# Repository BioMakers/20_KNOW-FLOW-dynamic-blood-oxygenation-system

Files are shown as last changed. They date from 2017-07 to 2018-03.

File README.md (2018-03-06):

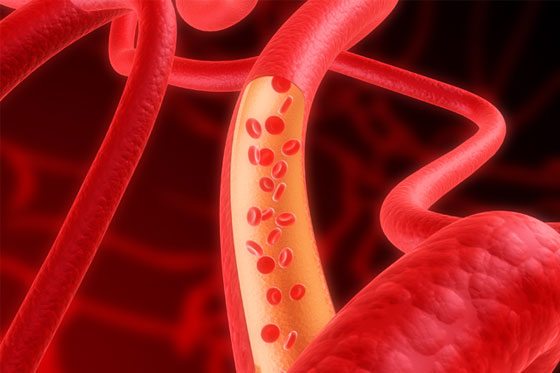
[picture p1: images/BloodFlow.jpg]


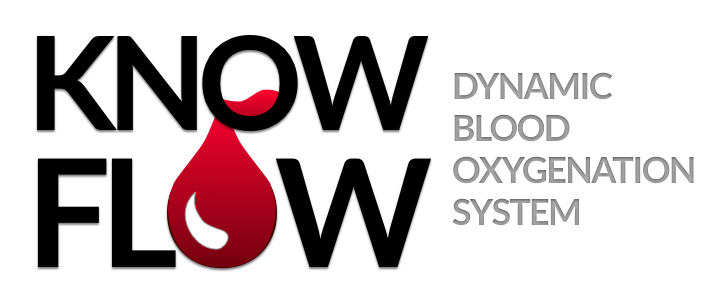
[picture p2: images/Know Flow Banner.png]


## The Idea

The aim of the project is to design and build a low-cost programmable system for flowing liquids through a network of tubes. The flow speed and direction, and fluid mixing via additional injection sites, will be controlled and monitored using a touchscreen interface connected to a peristaltic pump and a 3D-printed syringe pump. Moreover, the touchscreen will have the option for adjustment and display of fluid properties measurable using a pH/pO2/flow sensor array. This will enable control and monitoring of dynamic processes such as changes in blood oxygenation for study of various conditions including sickle cell anaemia and thalassaemia. It will also be possible to artificially perfuse an ex vivo organ such as the mouse or rat liver. In addition, the flow system will be suitable for integration into an imaging device, such as an optoacoustic tomography (OT) scanner, allowing the device to be calibrated for accurate measurements of flow and fluid properties.

## The Team (*Primary contact)

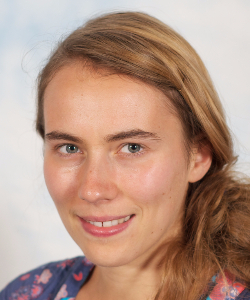
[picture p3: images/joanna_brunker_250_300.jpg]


**Joanna Brunker***     
CRUK Cambridge Institute, University of Cambridge

Jo is a postdoctoral research fellow with a PhD in measuring flow using optoacoustics, so will contribute to the design of the flow setup and subsequent testing in an optoacoustic scanner.

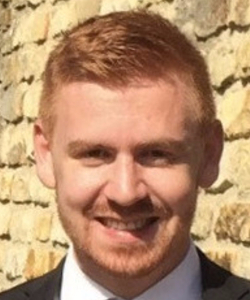
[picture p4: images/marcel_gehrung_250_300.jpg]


**Marcel Gehrung**          
CRUK Cambridge Institute, University of Cambridge

Marcel is a German Masters student studying for six months in Cambridge. He has a background in programming, machine learning, and cell biology, so will help to program the flow system and analyse the multi-parametric biological data.

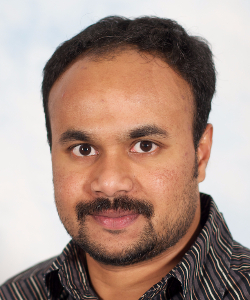
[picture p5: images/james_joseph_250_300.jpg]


**James Joseph**                
Department of Physics, University of Cambridge

James built optoacoustic imaging systems during his PhD, and is characterising imaging system stability for his postdoctoral research. He will therefore contribute to the design and engineering of the flow system and reliability testing. James also has experience with 3D printing.

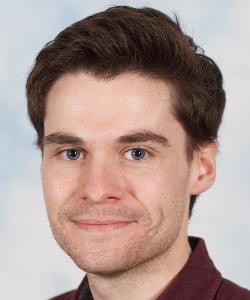
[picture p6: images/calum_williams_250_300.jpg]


**Calum Williams**
Department of Engineering, University of Cambridge

Calum’s post-doc follows his PhD in optical engineering, in which he fabricated and characterised various optical devices. He will contribute to 3D printing, programming, and optical sensing.

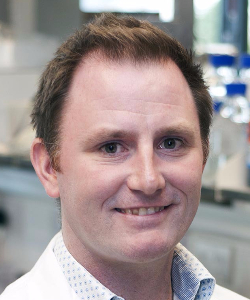
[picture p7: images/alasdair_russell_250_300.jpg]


**Alasdair Russell**          
CRUK Cambridge Institute, University of Cambridge

Al is Head of Pre-Clinical Genome Editing at the CRUK Cambridge Institute. He has a PhD involving haematology, so will contribute expertise on blood properties, help to analyse blood measurements, and direct the development of the flow system for additional haematological applications.

## Project proposal

### Problem and biological system

The blood circulation system plays a critical role in the function of healthy and diseased organisms. Assessment of blood flow, blood oxygenation and tissue perfusion is key to understanding numerous conditions ranging from sickle-cell anaemia to tumour hypoxia. Various techniques, including Doppler ultrasound and laser Doppler, exist for non-invasive assessment of flow in the blood circulation system. Emerging techniques, such as optoacoustic tomography (OT), have the potential to characterise blood absorption enabling measurement of oxygen concentration. However, without independent ex vivo assessment of flow, oxygenation and perfusion, these in vivo measurements remain un-calibrated and of limited value. Studies of flow ex vivo could be accomplished using a vessel-mimicking network of tubes, through which blood (or other fluids) can flow in a controlled manner. As yet there is no such programmable system readily available for real-time assessment of fluid flow.

<p align="center">
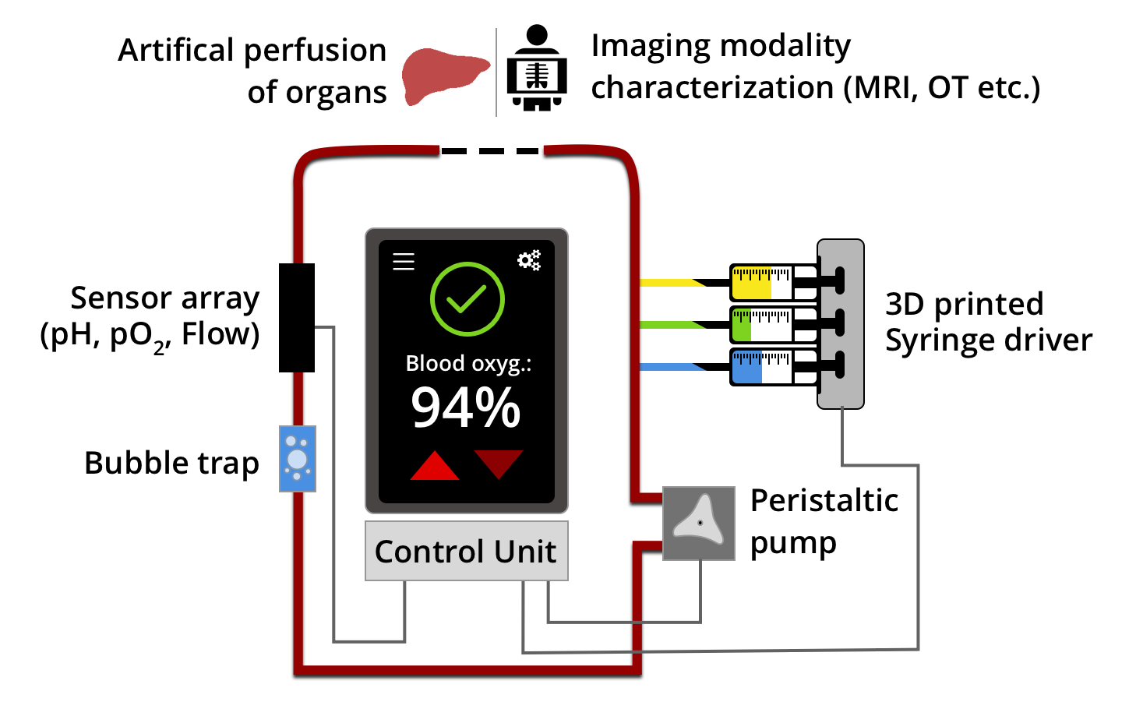
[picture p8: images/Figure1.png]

<p align="center">
Figure 1: Schematic of the low-cost programmable system for simulating flow in biological organisms. MRI: Magnetic Resonance Imaging; OT: Optoacoustic Tomography; pO2: partial pressure of oxygen.

### Design goals

The project will involve designing and building a low-cost programmable flow system for assessing physiologically relevant fluid properties. A schematic of the proposed system is shown in Figure 1. First, a basic prototype of the flow system will be assembled using tubing, a syringe pump, a peristaltic pump, and a sensor array already available in the laboratory. This system will be manually tested for consistent, bubble-free flow. The subsequent goals are described below.

1. Programming the flow system with integrated touch screen control

The peristaltic pump, syringe pump, and sensor array will be programmed for operation via a touchscreen interface (Figure 1). This will be achieved using the £250 Starter Kit provided, together with additional components as required.

2. Building low-cost versions of the pumps

A low-cost peristaltic pump will be built from a pump head and motor (Table 2).
The syringe pump will be 3D printed (instructions available) at an estimated cost of less than £400 (Table 2), which is a small fraction of the price for an off-the-shelf pump (>£3,000). It will have capacity for three syringes allowing injection of additional fluids so that properties such as blood oxygenation, or dye concentration, can be controlled and monitored.

3. Building tube networks

Initial studies with a single tube will be extended to more complex tube networks such as those representing vessels in the circulatory system (Figure 2). One option for achieving this would be to 3D print a structure based on a Computed Tomography (CT) image of a blood vessel network.

<p align="center">
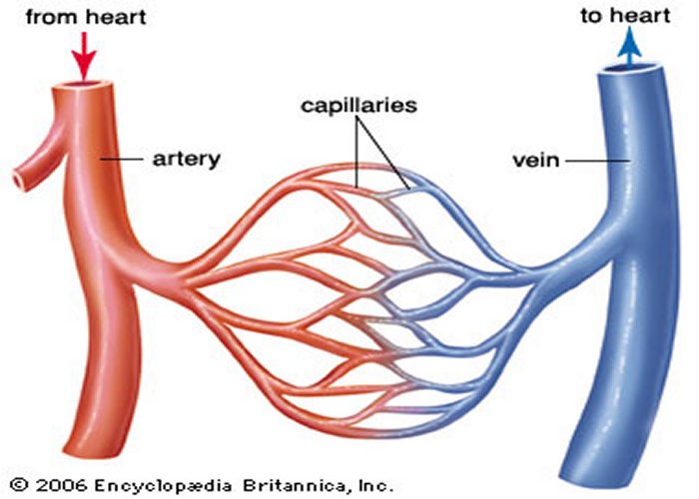
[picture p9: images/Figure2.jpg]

<p align="center">
Figure 2: Schematic of a complex tube network representing vessels in the circulatory system.

### Project implementation

4. Blood oxygenation studies

Although the flow system will be suitable for investigating many different fluid properties, the focus of this project is to investigate blood oxygenation. Assessments will be made of blood samples from different species (e.g. human, mouse, rabbit), particular sub-groups (e.g. high-performing athletes), and in different disease conditions (e.g. sickle-cell anaemia, thalassaemia). The measurements will be used to validate blood oxygenation (sO2) measurements acquired using independent imaging devices, in particular an optoacoustic tomography (OT) scanner. Blood will be chemically oxygenated or deoxygenated by injecting appropriate solutions (hydrogen peroxide or sodium hydrosulfite) into the system; the change in oxygenation will be monitored using an oxygen sensitive probe, and displayed on the touchscreen. This will validate simultaneously acquired OT sO2 measurements.

5. Artificial perfusion of organs

The ultimate goal of the project is to assess organ perfusion. This would entail delivery of blood from the tube network into an ex vivo organ such as the liver, followed by monitoring of the changes in flow and blood oxygenation.

### Proposed outcome and benefits

The flow system provides a versatile touchscreen-operated platform for investigation of various fluids, with an emphasis on blood. Measurement of physiological relevant parameters such as blood oxygenation will enable studies of haemoglobin disorders such as sickle-cell anaemia, and assessment of tissue perfusion. These measurements can also be used to validate data acquired simultaneously from independent imaging and flowmetry systems. The low cost of the system will enable mass production and distribution to other laboratories for easily operated, real-time flow studies.

Our preliminary measurements using our flow system were presented at an international conference, SPIE Photonics West, in San Francisco (January 2018). A peer-reviewed publication is currently being prepared with details of the flow system and its implementation.

<p align="center">

<p align="center">
Figure 3: Poster presented at SPIE Photonics West conference.

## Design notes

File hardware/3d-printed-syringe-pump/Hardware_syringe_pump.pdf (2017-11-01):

Tabel

1:

Necessary metal

parts

and

the

total

price

# | material | specifications

2 | M10 bolts | length: 220mm; threaded on
| | 50mm
1 | M5 threaded bar | Length: 1m
2 | M6 bolts | 80mm
2 | M6 wingnuts | /
2 | M5 bolts | Length: 40mm
2 | M5 wingnuts | /
2 | M5 washers | Diameter: 10mm
1 | Z-coupler | 5mm to 5mm
1 | Ball bearing | inside diameter: 5mm
| | outside diameter: 16mm
Total price | <5€

Tabel

2:

Necessary

electronics for

the

syringe

pump

with

prices

# | material | specifications | Price (€)

1 1.8° Nema 17
| stepper motor | -‐ 200 steps per revolution
| | -‐ Bidirectional | 26,51

### 1 Allegro A4988

| DMOS breakout
| board
- Simple step and direction control
| | interface
- Five different step resolutions:
| | full-step, half-step, quarter-step,
| | eighth-step, and sixteenth-step
- Adjustable current control lets
| | you set the maximum current
| | output with a potentiometer,
| | which lets you use voltages
| | above your stepper motor’s rated
| | voltage to achieve higher step
| | rates
- Intelligent chopping control that
| | automatically selects the correct
| | current decay mode (fast decay or
| | slow decay)
- Over-temperature thermal
| | shutdown, under-voltage lockout,
| | and crossover-current protection
- Short-to-ground and shorted-load
| | protection
- 4-layer, 2 oz copper PCB for
| | improved heat dissipation
- Exposed solderable ground pad
| | below the driver IC on the
| | bottom of the PCB | 6,99

### 1 Arduino UNO

| micro controller
- Based on the ATmega328
- 14 digital input/output pins (of which 6 can be used as PWM outputs)
- 6 analog inputs
- 16 MHz crystal oscillator
- USB connection
- power jack
- ICSP header
| | - reset button. | 24,2
1 | 9V battery | - power supply for the motor | 1,89

### 1 Breadboard &

| wires kit | / | 12,1
1 | USB-cable | Cable which connects the laptop too the
| | Arduino UNO | 2,42
Total price | 74,11

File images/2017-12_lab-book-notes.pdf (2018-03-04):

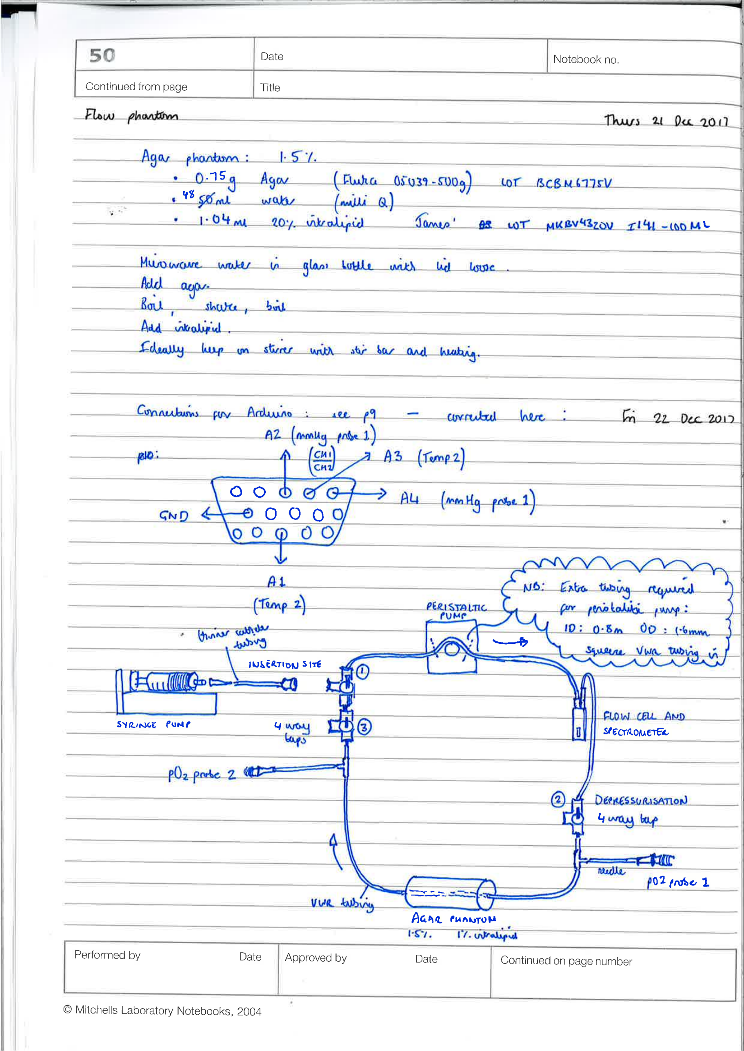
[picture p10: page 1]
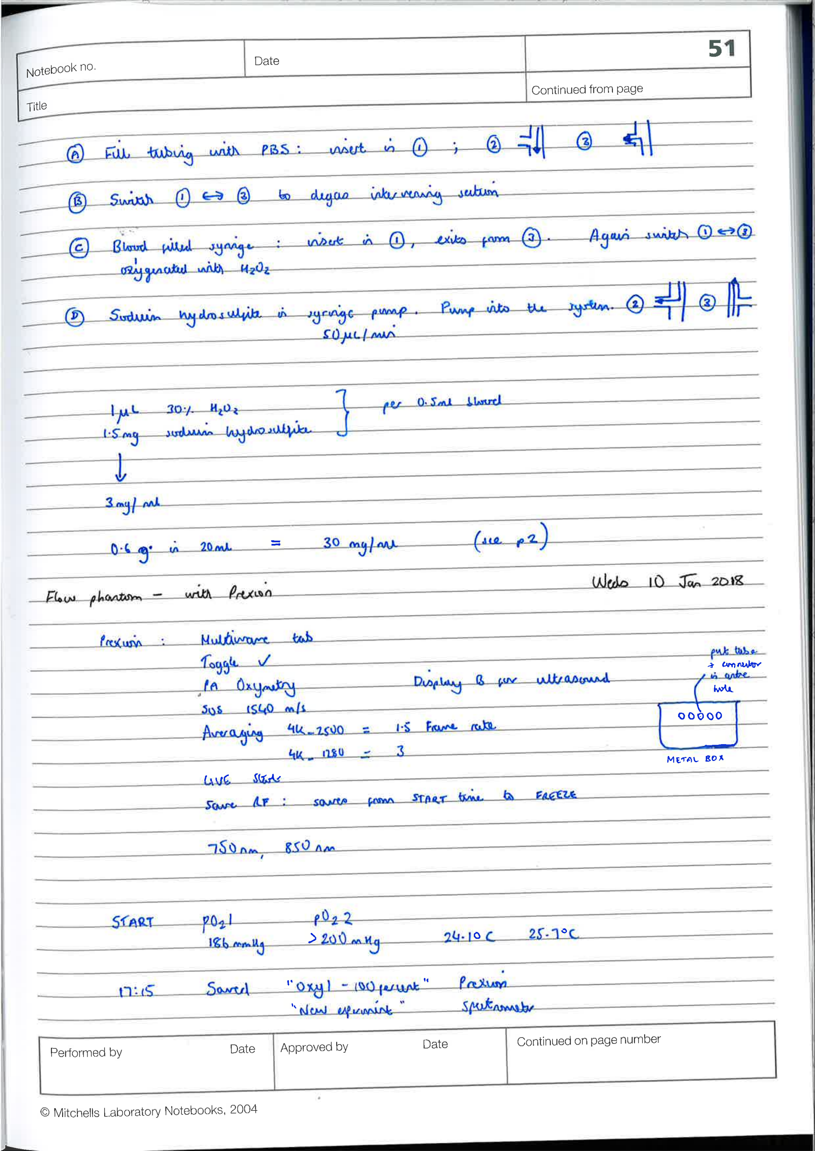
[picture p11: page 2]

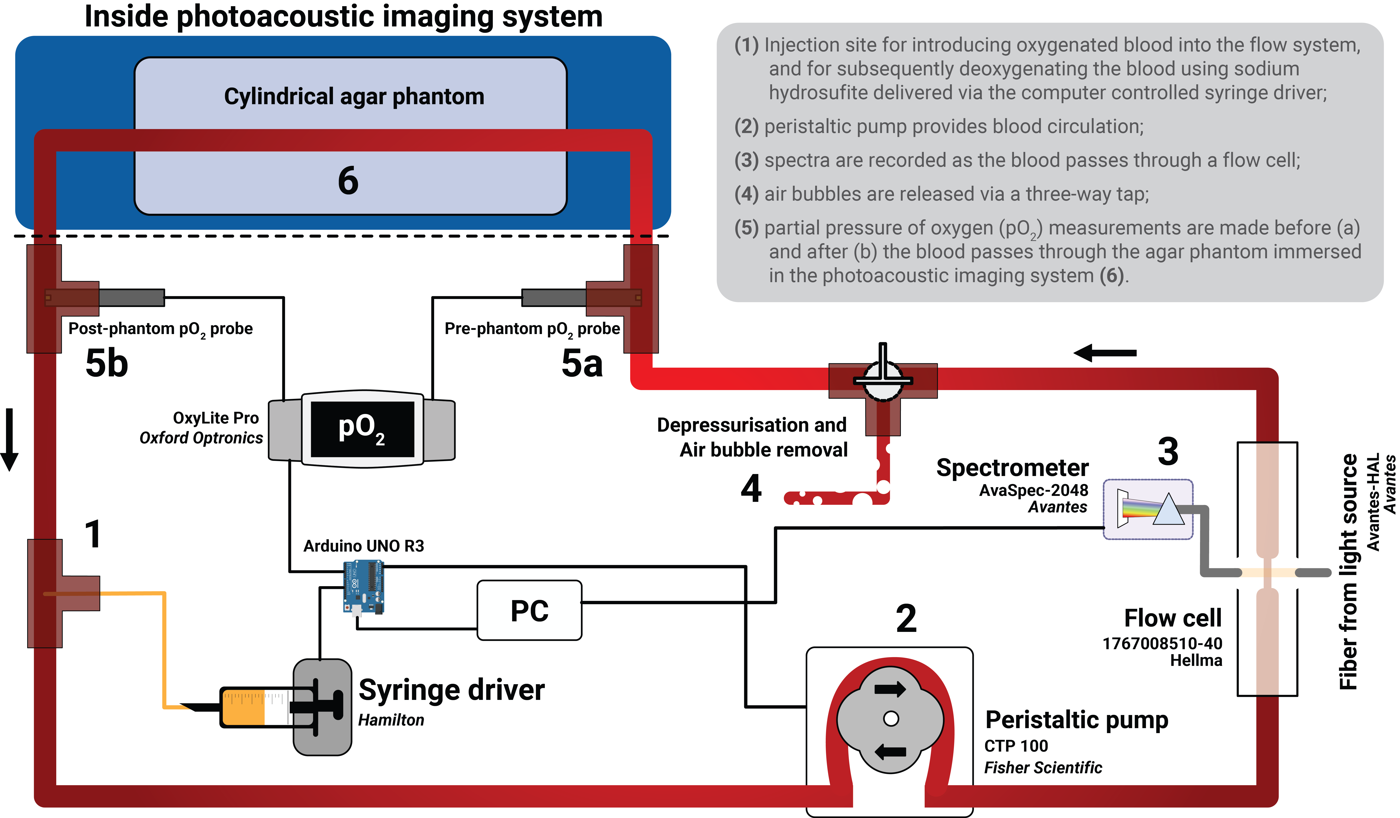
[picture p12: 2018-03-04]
images/flow-phantom.png

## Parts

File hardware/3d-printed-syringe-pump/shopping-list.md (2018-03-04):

# Shopping list

Item                    | Source            | Price (ex. VAT)
:---                    | :---              | :---
Nema 17 stepper motor   | [RS Components (798-3628)](https://uk.rs-online.com/web/p/stepper-motors/7983628 )                  | £36.43
Stepper motor driver    | [OneCall (HK01396)](https://www.velleman.eu/products/view/?id=415800&country=us&lang=en)  | £12.73
Arduino UNO        | [Rapid Electronics (73-4440)](https://www.rapidonline.com/arduino-uno-a000066-board-r3-73-4440)  | £15.35
Stainless steel threaded bar | [Toolstation (61139)](https://www.toolstation.com/shop/Screws+%26+Fixings/d90/Stainless+Range/sd1030/Stainless+Steel+Threaded+Bar/p61139)  | £1.48
2 x Hex Bolt Part Thread M10 x 220mm in A2 Stainless | [Westfield Fasteners](https://www.westfieldfasteners.co.uk/A2_ScrewBolt_HexHd_M10_THRpart.html)  | £4.52
Z coupler | [RS Components (435-1150)](https://uk.rs-online.com/web/p/rigid-shaft-couplings/4351150/)  | £22.65
Ball bearing | [RS Components (408-9754)](https://uk.rs-online.com/web/p/ball-bearings/4089754/)  | £2.43
M6 wing nuts | [RS Components (248-4343)](https://uk.rs-online.com/web/p/wing-nuts/2484343/) | £24.13
M6 bolts | [RS Components (917-3129)](https://uk.rs-online.com/web/c/fasteners-fixings/screws-bolts/hex-bolts/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) | £12.64
M5 wing nuts | [RS Components (248-4337)](https://uk.rs-online.com/web/p/wing-nuts/2484337/) | £23.52
M5 bolts | [RS Components (917-3090)](https://uk.rs-online.com/web/p/hex-bolts/9173090/) | £6.41

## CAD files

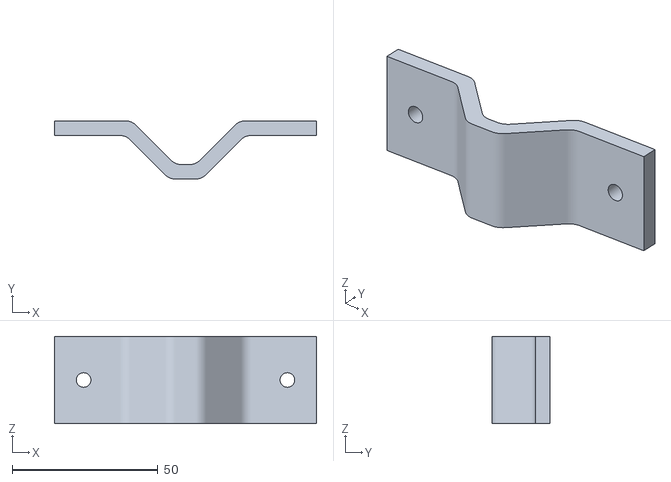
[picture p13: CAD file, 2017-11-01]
hardware/3d-printed-syringe-pump/Block_C_big_v2_excavated_oriented.stl
90.0 x 20.0 x 30.0

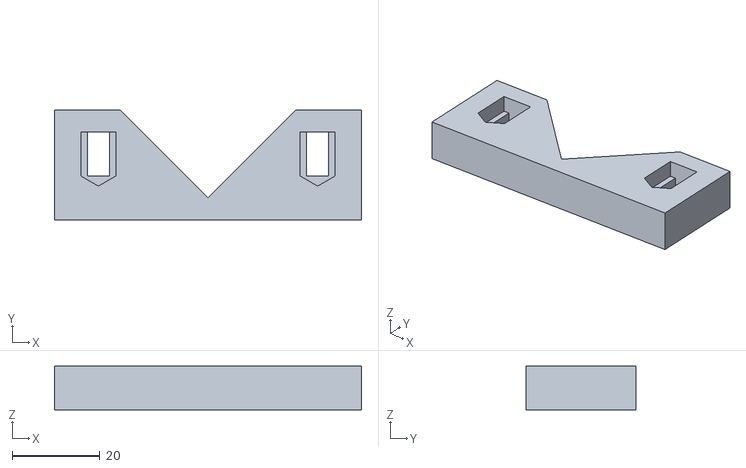
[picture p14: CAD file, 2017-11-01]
hardware/3d-printed-syringe-pump/Block_E_v5_excavated_oriented.stl
70.0 x 25.0 x 10.00

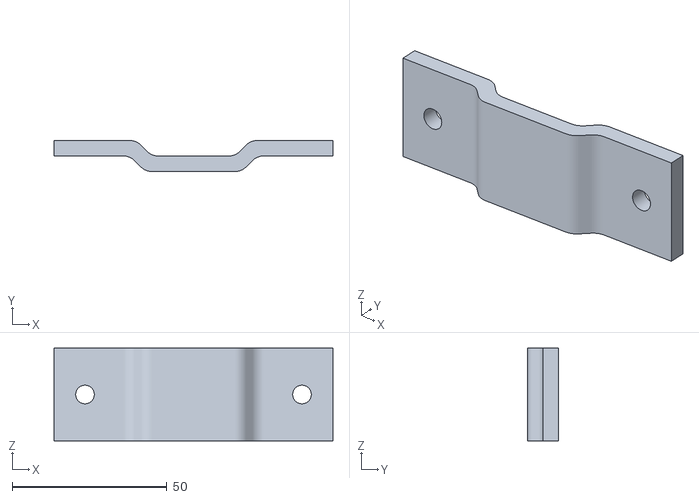
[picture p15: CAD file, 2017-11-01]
hardware/3d-printed-syringe-pump/Block_C_small_v3_excavated_oriented.stl
90.0 x 10.00 x 30.0

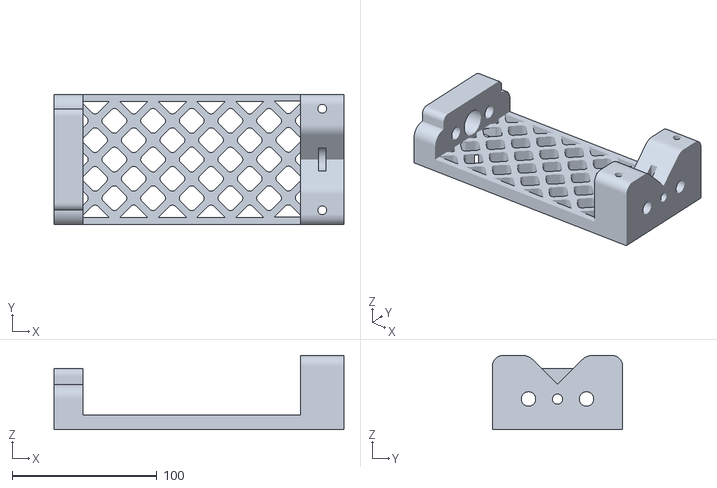
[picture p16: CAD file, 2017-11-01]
hardware/3d-printed-syringe-pump/Block_ABF_v10_excavated.stl
200.0 x 90.0 x 51.1

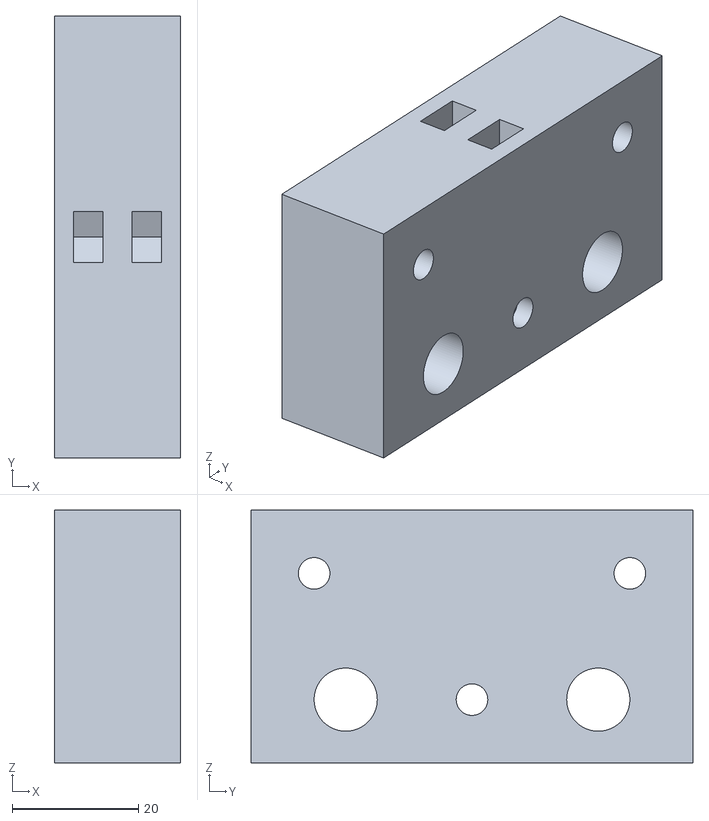
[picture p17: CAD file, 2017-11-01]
hardware/3d-printed-syringe-pump/Block_D_v10_excavated_oriented.stl
20.0 x 70.0 x 40.0

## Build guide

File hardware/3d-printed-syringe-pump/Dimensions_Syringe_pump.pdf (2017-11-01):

Syringe

pump
Parts | Dimensions
| (mm)
Block

A
Length | 150
width | 90
height | 10
Side

length

square

block | 13,856x13,856
Radius

rounded

edge

square

block 3
Block

B
length | 30
width | 90
height | 51,1
Radius

outside

rounded

edge | 7,5
Radius

inside

rounded

edge | 10
Triangular
hight | 20
Triangular
base | 40
Diameter

bolt

hole

(M10) | 10
Diameter

screw

hole

(M5) | 7
Radius

ball

bearing hole | 16
Widthness

ball

bearing hole | 5,5
Diameter

bolt

hole

(M6) | 6
Inner

diameter

hexagonal

hole

(M6) 11,547
Height

hexagonal hole

(M6) | 11
Block

F
Lenght | 20
width | 90
Height highest
rounding | 42,1
Radius

highest

rounding | 5
Height

lower

rounding | 31.1
Radius

lower

rounding | 10
Diameter

motor

coupler

hole | 20
Diameter

bolt

head

hole

(M10) | 25
Depth

bolt

head

hole

(M10) | 6
Bolt

head

square

hole

(M10) | 10x10
Diameter

bolt

hole

(M10) | 10
Small

diameter

bolt

hole

(M3) | 3
Big

diameter

bolt

hole

(M3) | 6
length bolt

hole

(M3) | 4
Block

AF
Length

of

bolt

hole | 30
Width

of

bolt

hole | 10
Heigth

of

bolt

hole | 9
Block

C (big

syringe)
Length | 30
Width
(total) | 90
-‐ upwards

face

of

the

upper

plate | 26,5711
-‐ downwards

face

of

the

upper plate | 24,5

-‐ upwards

face

of

the

lower

plate 27
-‐ downwards

face

of

het

lower plate | 31
Height | 5
Diameter

bolt

hole

(M6) | 6
Radius

rounded

edges | 5
Block

C

(small

syringe)
length | 30
Width
(total) | 90
-‐ upwards

face

of

the

upper

plate | 26,5
-‐ downwards

face

of

the

upper plate | 24,5

-‐ upwards

face

of

the

lower

plate 7
-‐ downwards

face

of

het

lower plate | 11
Height | 5
Diameter

bolt

hole

(M6) | 6
Radius

rounded

edges | 5
Block

D
Length | 20
width | 90
height | 40
Diameter

bolt

hole

(M10) | 10
Diameter

screw

hole

(M5) | 5
Inner

diameter

hexagonal

hole | 9,2376
Width

center

nut

holes | 8
Length

center

nut

holes | 4,7
Length

sideway

nut

holes | 4
Block

E
Length | 10
Width | 90
Height | 25
Triangular
height | 20
Triangular

base

length | 40
Length

sideway

holes | 10
Width

sideway

holes | 5
Height

sideway

holes | 10
Inner

diameter

nut

hole | 9,2376
Length

nut

hole | 4

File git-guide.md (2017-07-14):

Here are some loose guidlines meant to give you an idea of what information we expect to find in each repository. Feel free to present your documentation in the most accessible/suitable order and style but you **must** include project data relating to the headings below, if relevant to your project. Also, include your final proposal in the top directory.

[**A very good example**](https://github.com/Biological-Microsystems-Laboratory/micropipette)

Consider using [GitHub for desktop](https://desktop.github.com/), the user interface and experience is so much better than the web version of Github, in my opinion.

Lastly, follow [these](https://pages.github.com/) instructions if you want to style your github repository into a webpage like [so](https://biomakers.github.io/Example-repo/).

## Synopsis

A summary of your project. This is the 150 word description from your proposal. Include your project banner and photos of team members.

## Software

Explain functionality of software components (if any) as concisely as possible, developers should be able to figure out how your project solves their problem by looking at the code example. Ideally, this should be pseudo code or an abstract graphical representation of your code e.g entity relationship diagram. Consider adding a screenshot of your User Interface.

## Hardware

Explain how the hardware components (if any) of your project function as concisely as possible, including a short description of fabrication and assembly. Component suppliers and part numbers should be provided separately in a bill of materials, in a 'Hardware Folder'.

## Installation, Maintenance and Testing Guide

Provide instructions on usage, describe a test scheme and show how to run the tests with code and hardware configuration examples with some representative results.

## License

A short snippet describing the license (MIT, Apache, etc.) you have chosen to use

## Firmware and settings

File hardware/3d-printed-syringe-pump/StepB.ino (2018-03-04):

// --- Commande d'un StepStick/Driver A4988 ----------------------
// A4988_Test.ino
//
// Commande d'un moteur pas-à-pas à l'aide d'un pilote A4988 avec
//     Arduino.
//
// Un projet www.mchobby.be (vente de kit et composant)
// Meurisse D. - Licence CC-SA-BY
//
// Un tutoriel http://mchobby.be/wiki/index.php?title=A4988
// Ou Acheter un StepStick A4988
//    http://shop.mchobby.be/product.php?id_product=349
//

#define pinEnable 13 // Activation du driver/pilote
#define pinStep    9 // Signal de PAS (avancement)
#define pinDir     8 // Direction 


void setup(){
  Serial.begin(9600);
  Serial.println("Test A4988");
  
  pinMode( pinEnable, OUTPUT );
  pinMode( pinDir   , OUTPUT );
  pinMode( pinStep  , OUTPUT );
}

void loop(){
  int i = 0;
  
  digitalWrite( pinDir   , LOW); // Direction arriere
  digitalWrite( pinStep  , LOW);  // Initialisation de la broche step
  
  // Steps back xxxx steps. 1cm = 2500 steps
  for( i=0; i<2500; i++){
    Serial.println( i );
    digitalWrite( pinStep, HIGH );
    delay( 1 );
    digitalWrite( pinStep, LOW );
    delay( 1 );
  } 
  
  // Pas de step et pas d'ordre... 
  //   l'axe du moteur est donc bloqué 
  Serial.println("Axe bloqué + attendre 1 sec");
  delay( 1000 );
  
  // déblocage de l'axe moteur
  Serial.println("Deblocage axe");
  digitalWrite( pinEnable, HIGH ); // logique inversée
  
  // Fin et blocage du programme
  // Presser reset pour recommander
  Serial.println("Fin de programme");
  while( true );
}
